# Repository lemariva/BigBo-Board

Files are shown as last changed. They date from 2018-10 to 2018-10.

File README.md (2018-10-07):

# BigBo-Board

BigBo is a multi-target board for Energy Metering & Power Monitoring. It's the big brother of [PiCoBo](https://github.com/lemariva/PiCoBo-Board). I designed it using the MSP430F5529LP that is part of the MSP430 Texas Instruments family of low-power microcontrollers.

More info will be available on https://lemariva.com soon.

## Components
The board includes:
* CP2102 for UART communication (with ESD-Protection)
* Socket for a NRF24L01 module
* CD4504B: level shifter
* BQ27510-Q3: battery fuel gauge
* BQ24210DQCT: Li-Ion battery charger
* CAT24FC32UI: EEPROM memory
* TPS6300x: buck-boost converters (for 5V)
* MCP39F501: power-monitoring
* etc.

This board is a Energy Metering & Power Monitoring demonstration board with communication possibilities (0.1% error across 4000:1 dynamic range). I designed it near 2013, when home solutions were limited and expensive. The power energy metering & power monitoring functions are based on the [ARD00455](https://www.microchip.com/Developmenttools/ProductDetails/ARD00455) board.

The board can be supplied using:
* a battery (Li-Ion) which can be also charged
* 5V over the micro-usb connector
* 230V AC (not a typo error - 230V AC!). The floating 3.3V is generated using a LM1117. Check the HIGH-Voltage page on the schematic.

Additionally multiple pinouts are available to connect external sensors (e.g. DHT11), servo motors, LEDs etc. For testing uses it can be programmed using the MSP430F5529LP LaunchPad.

## PCB
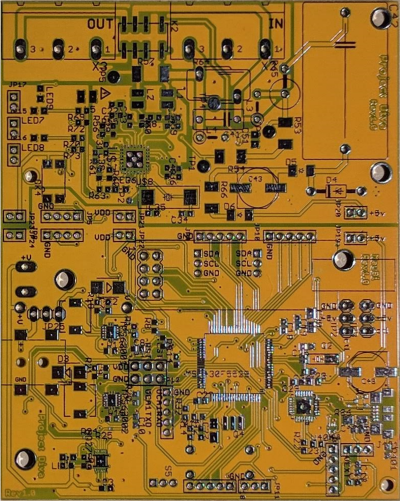
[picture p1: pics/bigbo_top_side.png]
PCB Board Top Side
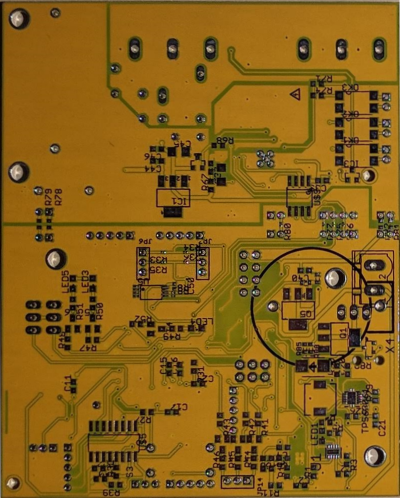
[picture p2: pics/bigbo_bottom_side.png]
PCB Board Bottom Side
|||
|:- |:-|

### Applications
* Energy Metering & Power Monitoring
* Smart switch
* Sensor measurement (Temperature etc.)
* LEDs control
* Communication
* etc.

### Revision
* 1.0 first version

### Disclaimer
Use at your own risk and be careful specially with the 230V AC part.

I ordered the board (I have 10 PCBs over here) but I didn't have enough time to solder the components. I've checked the design many times but errors could be over there. I'll be updating the code that I had for the board soon.

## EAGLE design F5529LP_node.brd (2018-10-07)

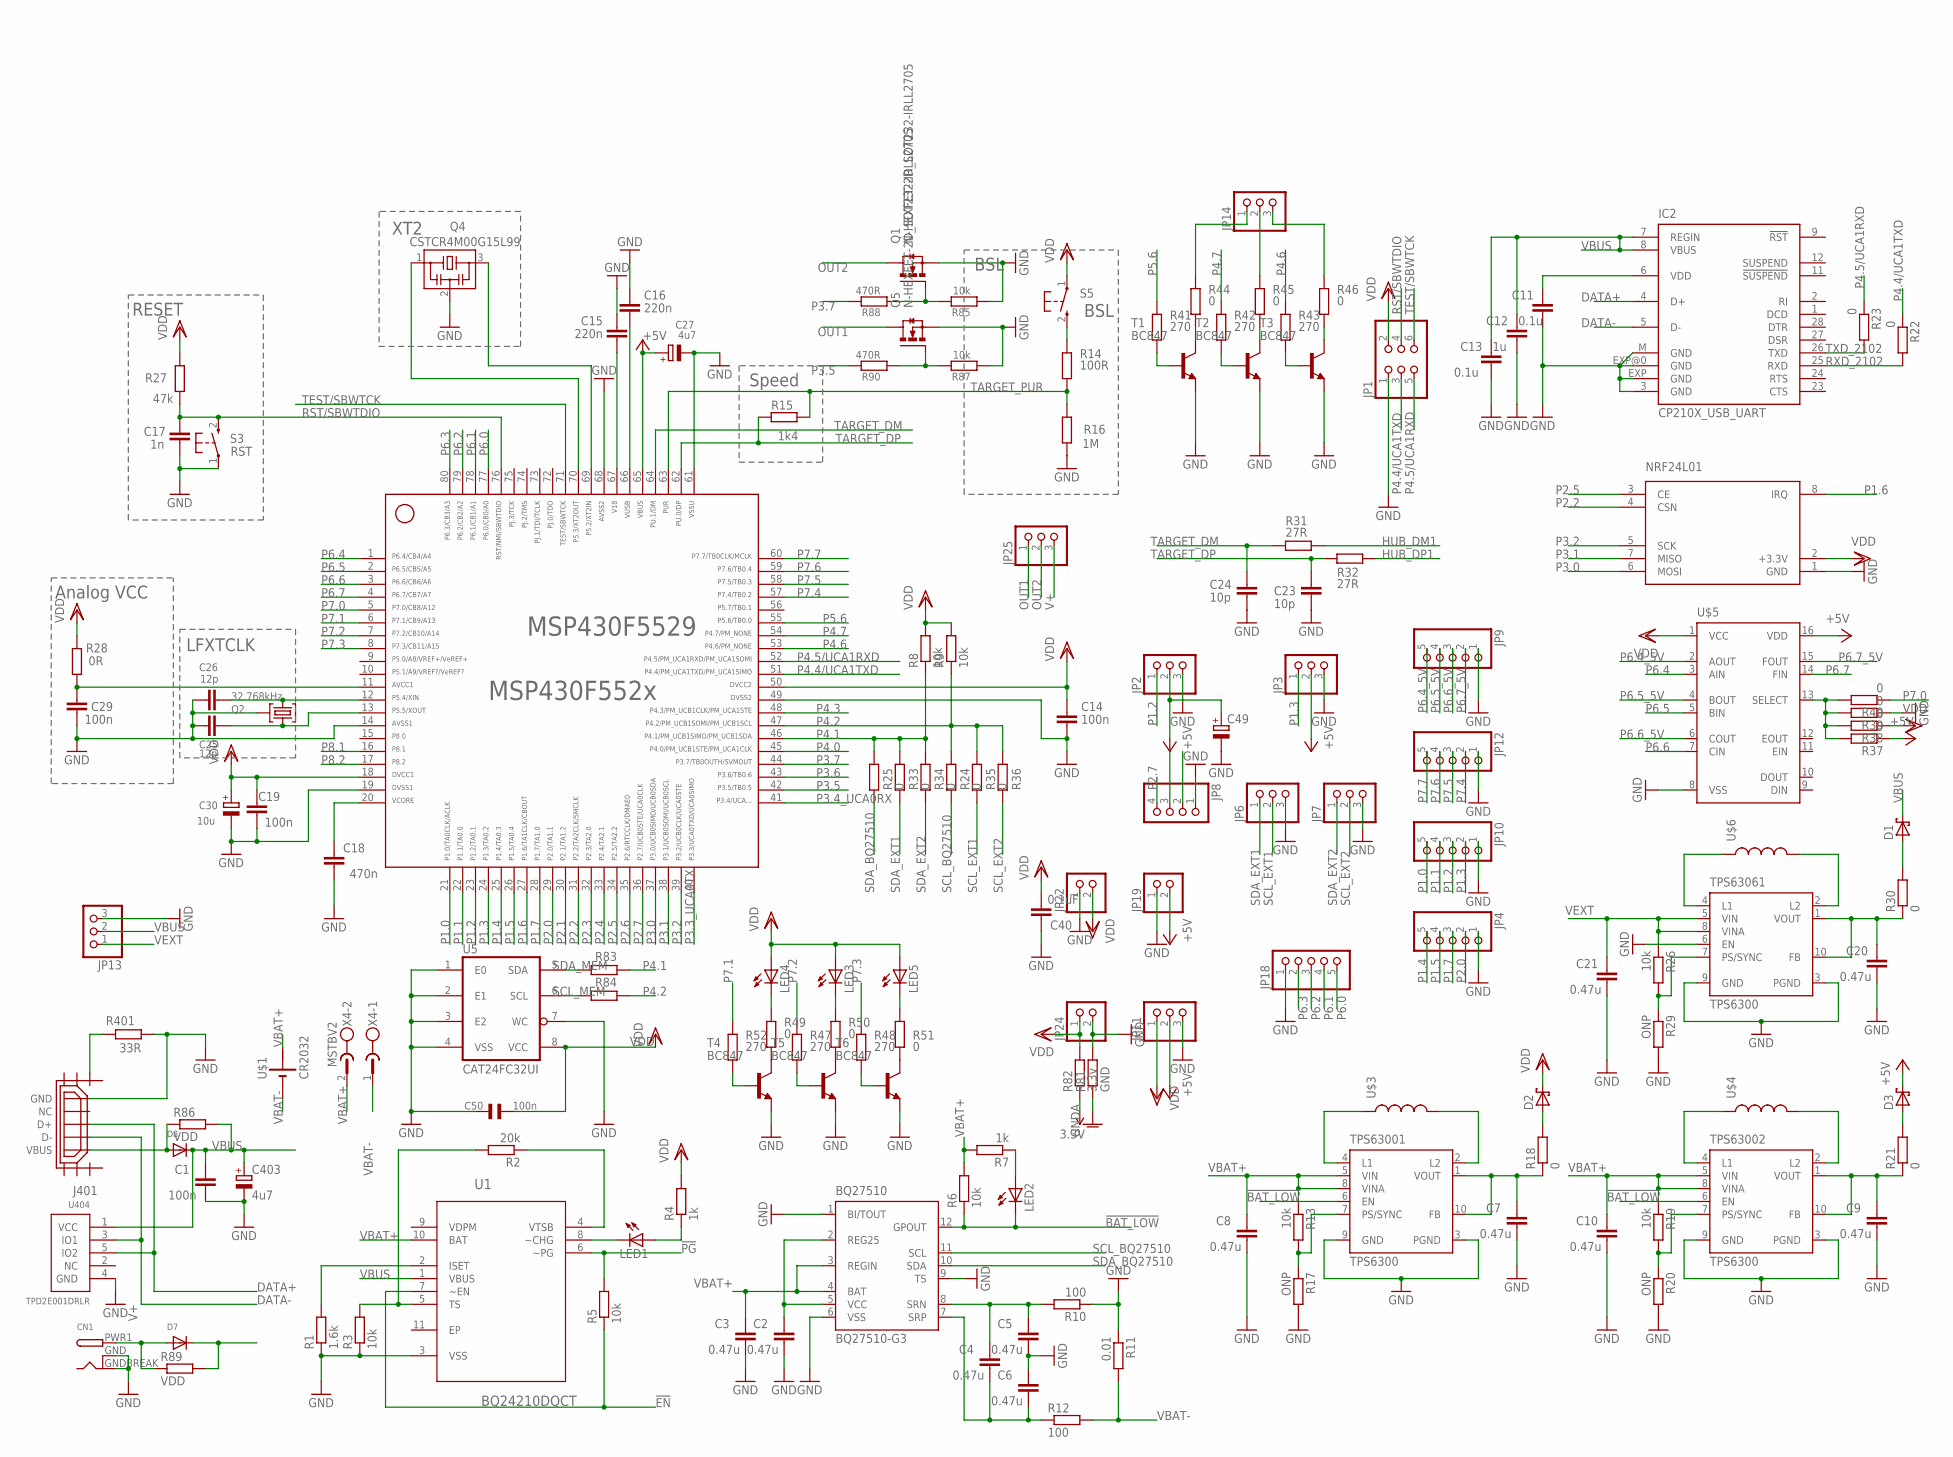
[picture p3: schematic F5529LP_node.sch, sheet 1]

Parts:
BQ27510: BQ27510-G3; DRZ
C1, C14, C19, C29: 100n; C0603
C2, C3, C4, C5, C6, C7, C8, C9, C10, C20, C21: 0.47u; C0603
C11, C13: 0.1u; C0603
C12: 1u; C0603
C15, C16: 220n; C0603
C17: 1n; C0603
C18: 470n; C0603
C23, C24: 10p; C0603
C25, C26: 12p; C0603
C27, C403: 4u7; A/3216-18R
C30: 10u; A/3216-18R
C40: 0.1uF; C0603
C49: CPOL-EUF; PANASONIC_F
C50: 100n; 0402
CN1: DCBARRELSMT; DCJACK_2MM_SMT
D1, D2, D3: SCHOTTKY-DIODE; DIODE_SMB
D7, D8: DIODESOT23_REFLOW; SOT23-R
IC2: CP210X_USB_UART; MLP28
J401: USB_MICRO_FLIPPED; HIROSE-ZX62R-B-5P
JP1: PINHD-2X3; 2X03
JP2, JP3, JP25: PINHD-1X3; 1X03
JP4, JP9, JP10, JP12, JP18: PINHD-1X5_2.00; 1X05M
JP6, JP7, JP11, JP13, JP14: PINHD-1X3_2.00; 1X03M
JP8: PINHD-1X4_2.00; 1X04M
JP19, JP22, JP24: PINHD-1X2_2.00; 1X02M
LED1, LED2, LED3, LED4, LED5: LEDSML0805; SML0805
MSP430F5529: MSP430F5529IPNR; PN80
NRF24L01: NRF24L01HP; NRF24L01_HP
Q1, Q5: N-HEXFET-2D_SOT232-IRLL2705; SOT223
Q2: 32.768kHz; MS3V-T1R
Q4: CSTCR4M00G15L99; MURATA-FILTER_CSTCR
R1: 1.6k; R0603
R2: 20k; R0603
R3, R5, R6, R8, R9, R13, R19, R26: 10k; R0603
R4, R7: 1k; R0603
R10, R12: 100; R0603
R11: 0.01; R0603
R14: 100R; R0603
R15: 1k4; R0603
R16: 1M; R0603
R17, R20, R29: ONP; R0603
R18, R21, R22, R23, R30, R37, R38, R39, R40, R44, R45, R46, R49, R50, R51: 0; R0603
R24, R25, R33, R34, R35, R36, R83, R84: 0; R0201
R27: 47k; R0603
R28: 0R; R0603
R31, R32: 27R; R0603
R41, R42, R43, R47, R48, R52: 270; R0603
R81: GND; R0402
R82: 3.3v; R0402
R85, R87: 10k; 0603
R86, R89: VDD; R0201
R88, R90: 470R; 0603
R401: 33R; R0603
S3: RST; PBTH
S5: BSL; PBTH
T1, T2, T3, T4, T5, T6: BC847; SOT23
TPS63001, TPS63002, TPS63061: TPS6300; DRC-S-PVSON-N10
U1: BQ24210DQCT; SON50P200X300X80-11N
U5: CAT24FC32UI; TSSOP8
U404: TPD2E001DRLR; TPD2E001-DRL
U$1: CR2032
U$3, U$4, U$6: INDUCTOR-B82462G; B82462G
U$5: CD4504B; SOIC16
X4: MSTBV2

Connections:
3.3V: R82.1; also elsewhere on the board
!BAT_LOW: BQ27510.12 (GPOUT), LED2.C, R6.1, TPS63001.6 (EN), TPS63002.6 (EN)
!EN: R5.1, U1.7 (~EN)
!PG: R5.2, U1.6 (~PG)
+5V: C27.+, C49.+, D3.C (A), JP2.2, JP3.2, JP11.2, JP19.2, MSP430F5529.65, R37.1, U$5.16 (VDD); also elsewhere on the board
AVCC: C29.1, MSP430F5529.11, R28.1
DATA+: IC2.4 (D+), J401.D+, U404.5 (IO2)
DATA-: IC2.5 (D-), J401.D-, U404.3 (IO1)
GND: BQ27510.1 (BI/TOUT), BQ27510.6 (VSS), BQ27510.9 (TS), C1.2, C2.2, C3.2, C5.2, C6.1, C7.2, C8.2, C9.2, C10.2, C11.2, C12.2, C13.2, C14.2, C15.2, C16.2, C17.2, C18.1, C19.1, C20.2, C21.2, C23.2, C24.2, C25.1, C26.1, C27.-, C29.2, C30.-, C40.1, C49.-, C50.2, C403.-, CN1.GND (GNDBREAK), CN1.GNDBREAK (GND), IC2.3 (GND), IC2.EXP (GND), IC2.EXP@0 (GND), IC2.M (GND), J401.GND, JP1.1, JP2.3, JP3.3, JP4.1, JP6.3, JP7.3, JP8.1, JP9.1, JP10.1, JP11.3, JP12.1, JP13.3, JP18.1, JP19.1, JP22.1, JP24.2, MSP430F5529.14, MSP430F5529.19, MSP430F5529.49, MSP430F5529.61, MSP430F5529.68, NRF24L01.1 (GND), Q1.3 (S), Q2.P3 (GND), Q4.2, Q5.3 (S), R1.1, R3.1, R10.1, R11.1, R16.1, R17.2, R20.2, R29.2, R39.1, R81.2, R85.1, R87.1, R401.2, S3.1, T1.2 (E), T2.2 (E), T3.2 (E), T4.2 (E), T5.2 (E), T6.2 (E), TPS63001.3 (PGND), TPS63001.9 (GND), TPS63002.3 (PGND), TPS63002.9 (GND), TPS63061.3 (PGND), TPS63061.6 (EN), TPS63061.9 (GND), U1.3 (VSS), U5.1 (E0), U5.2 (E1), U5.3 (E2), U5.4 (VSS), U5.7 (WC), U404.4 (GND), U$5.8 (VSS); also elsewhere on the board
GNDA: R81.1; also elsewhere on the board
HUB_DM1: R31.1
HUB_DP1: R32.1
unnamed: R1.2, U1.2 (ISET)
unnamed: R2.1, U1.4 (VTSB)
unnamed: R2.2, R3.2, U1.5 (TS)
unnamed: R14.1, S5.2 (S)
unnamed: LED1.C, U1.8 (~CHG)
unnamed: LED1.A, R4.1
unnamed: BQ27510.2 (REG25), BQ27510.5 (VCC), C2.1
unnamed: TPS63002.4 (L1), U$4.P$1 (1)
unnamed: LED2.A, R7.1
unnamed: J401.SHIELD1, R401.1
unnamed: BQ27510.8 (SRN), C4.1, C5.1, R10.2
unnamed: TPS63001.4 (L1), U$3.P$1 (1)
unnamed: TPS63001.2 (L2), U$3.P$2 (2)
unnamed: BQ27510.7 (SRP), C4.2, C6.2, R12.1
unnamed: TPS63002.2 (L2), U$4.P$2 (2)
unnamed: R13.2, R17.1, TPS63001.7 (PS/SYNC)
unnamed: R19.2, R20.1, TPS63002.7 (PS/SYNC)
unnamed: C9.1, R21.1, TPS63002.1 (VOUT), TPS63002.10 (FB)
unnamed: C7.1, R18.1, TPS63001.1 (VOUT), TPS63001.10 (FB)
unnamed: C11.1, IC2.6 (VDD)
unnamed: TPS63061.4 (L1), U$6.P$1 (1)
unnamed: TPS63061.2 (L2), U$6.P$2 (2)
unnamed: R26.2, R29.1, TPS63061.7 (PS/SYNC)
unnamed: C20.1, R30.1, TPS63061.1 (VOUT), TPS63061.10 (FB)
unnamed: R37.2, R38.2, R39.2, R40.2, U$5.13 (SELECT)
unnamed: R41.2, T1.1 (B)
unnamed: R42.2, T2.1 (B)
unnamed: R43.2, T3.1 (B)
unnamed: R46.2, T3.3 (C)
unnamed: JP14.1, R44.1
unnamed: JP14.2, R45.1
unnamed: JP14.3, R46.1
unnamed: R44.2, T1.3 (C)
unnamed: R45.2, T2.3 (C)
unnamed: D1.A (C), R30.2
unnamed: D2.A (C), R18.2
unnamed: D3.A (C), R21.2
unnamed: R47.2, T5.1 (B)
unnamed: R48.2, T6.1 (B)
unnamed: R51.2, T6.3 (C)
unnamed: LED4.C, R49.1
unnamed: LED3.C, R50.1
unnamed: LED5.C, R51.1
unnamed: R49.2, T4.3 (C)
unnamed: R50.2, T5.3 (C)
unnamed: R52.2, T4.1 (B)
unnamed: Q1.1 (G), R85.2, R88.1
unnamed: D8.1 (A), J401.VBUS, R86.1
unnamed: Q5.1 (G), R87.2, R90.1
OUT1: JP25.1, Q5.2 (D), Q5.4 (D)
OUT2: JP25.2, Q1.2 (D), Q1.4 (D)
P1.0: JP10.5, MSP430F5529.21
P1.1: JP10.4, MSP430F5529.22
P1.2: JP2.1, JP10.3, MSP430F5529.23
P1.3: JP3.1, JP10.2, MSP430F5529.24
P1.4: JP4.5, MSP430F5529.25
P1.5: JP4.4, MSP430F5529.26
P1.6: MSP430F5529.27, NRF24L01.8 (IRQ)
P1.7: JP4.3, MSP430F5529.28
P2.0: JP4.2, MSP430F5529.29
P2.1: MSP430F5529.30
P2.2: MSP430F5529.31, NRF24L01.4 (CSN)
P2.3: MSP430F5529.32
P2.4: MSP430F5529.33
P2.5: MSP430F5529.34, NRF24L01.3 (CE)
P2.6: MSP430F5529.35
P2.7: JP8.4, MSP430F5529.36; also elsewhere on the board
P3.0: MSP430F5529.37, NRF24L01.6 (MOSI)
P3.1: MSP430F5529.38, NRF24L01.7 (MISO)
P3.2: MSP430F5529.39, NRF24L01.5 (SCK)
P3.3_UCA0TX: JP8.2, MSP430F5529.40; also elsewhere on the board
P3.4_UCA0RX: JP8.3, MSP430F5529.41; also elsewhere on the board
P3.5: MSP430F5529.42, R90.2
P3.6: MSP430F5529.43
P3.7: MSP430F5529.44, R88.2
P4.0: MSP430F5529.45
P4.1: MSP430F5529.46, R8.1, R25.1, R33.1, R34.1, R83.2
P4.2: MSP430F5529.47, R9.1, R24.1, R35.1, R36.1, R84.2
P4.3: MSP430F5529.48
P4.4/UCA1TXD: JP1.3, MSP430F5529.51, R22.1
P4.5/UCA1RXD: JP1.5, MSP430F5529.52, R23.1
P4.6: MSP430F5529.53, R43.1
P4.7: MSP430F5529.54, R42.1
P5.2/XT2IN: MSP430F5529.69, Q4.3
P5.3/XT2OUT: MSP430F5529.70, Q4.1
P5.4/XIN: C26.2, MSP430F5529.12, Q2.P2 (2)
P5.5/XOUT: C25.2, MSP430F5529.13, Q2.P1 (1)
P5.6: MSP430F5529.55, R41.1
P6.0: JP18.5, MSP430F5529.77
P6.1: JP18.4, MSP430F5529.78
P6.2: JP18.3, MSP430F5529.79
P6.3: JP18.2, MSP430F5529.80
P6.4: MSP430F5529.1, U$5.3 (AIN)
P6.4_5V: JP9.5, U$5.2 (AOUT)
P6.5: MSP430F5529.2, U$5.5 (BIN)
P6.5_5V: JP9.4, U$5.4 (BOUT)
P6.6: MSP430F5529.3, U$5.7 (CIN)
P6.6_5V: JP9.3, U$5.6 (COUT)
P6.7: MSP430F5529.4, U$5.14 (FIN)
P6.7_5V: JP9.2, U$5.15 (FOUT)
P7.0: MSP430F5529.5, R40.1
P7.1: MSP430F5529.6, R52.1
P7.2: MSP430F5529.7, R47.1
P7.3: MSP430F5529.8, R48.1
P7.4: JP12.2, MSP430F5529.57
P7.5: JP12.3, MSP430F5529.58
P7.6: JP12.4, MSP430F5529.59
P7.7: JP12.5, MSP430F5529.60
P8.1: MSP430F5529.16
P8.2: MSP430F5529.17
PWPD: BQ27510.EXP@1 (PWPD), BQ27510.EXP@2 (PWPD), BQ27510.EXP@3 (PWPD), BQ27510.EXP@4 (PWPD), BQ27510.EXP@5 (PWPD), BQ27510.EXP@6 (PWPD), BQ27510.EXP@7 (PWPD), BQ27510.EXP@8 (PWPD), BQ27510.EXP@9 (PWPD)
RST/SBWTDIO: C17.1, JP1.4, MSP430F5529.76, R27.1, S3.2 (S)
RXD_2102: IC2.25 (RXD), R22.2
SCL_BQ27510: BQ27510.11 (SCL), R24.2
SCL_EXT1: JP6.2, R35.2
SCL_EXT2: JP7.2, R36.2
SCL_MEM: R84.1, U5.6 (SCL)
SDA_BQ27510: BQ27510.10 (SDA), R25.2
SDA_EXT1: JP6.1, R33.2
SDA_EXT2: JP7.1, R34.2
SDA_MEM: R83.1, U5.5 (SDA)
TARGET_DM: C24.1, MSP430F5529.64, R31.2
TARGET_DP: C23.1, MSP430F5529.62, R15.2, R32.2
TARGET_PUR: MSP430F5529.63, R14.2, R15.1, R16.2
TARGET_VUSB: C16.1, MSP430F5529.66
TEST/SBWTCK: JP1.6, MSP430F5529.71
TXD_2102: IC2.26 (TXD), R23.2
V18: C15.1, MSP430F5529.67
V+: CN1.PWR1 (PWR), D7.1 (A), JP25.3, R89.1
VBAT+: BQ27510.3 (REGIN), BQ27510.4 (BAT), C3.1, C8.1, C10.1, R6.2, R7.2, R13.1, R19.1, TPS63001.5 (VIN), TPS63001.8 (VINA), TPS63002.5 (VIN), TPS63002.8 (VINA), U1.10 (BAT), U$1.P$1 (+), X4.2
VBAT-: R11.2, R12.2, U$1.P$2 (-), X4.1
VBUS: C1.1, C12.1, C13.1, C403.+, D1.C (A), D7.3 (C), D8.3 (C), IC2.7 (REGIN), IC2.8 (VBUS), JP13.2, R86.2, R89.2, U1.1 (VBUS), U404.1 (VCC)
VCORE: C18.2, MSP430F5529.20
VDD: C14.1, C19.2, C30.+, C40.2, C50.1, D2.C (A), JP1.2, JP11.1, JP22.2, JP24.1, LED3.A, LED4.A, LED5.A, MSP430F5529.18, MSP430F5529.50, NRF24L01.2 (+3.3V), R4.2, R8.2, R9.2, R27.2, R28.2, R38.1, R82.2, S5.1, U5.8 (VCC), U$5.1 (VCC); also elsewhere on the board
VEXT: C21.1, JP13.1, R26.1, TPS63061.5 (VIN), TPS63061.8 (VINA)

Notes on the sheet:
RESET
LFXTCLK
XT2
BSL
Speed
Analog VCC

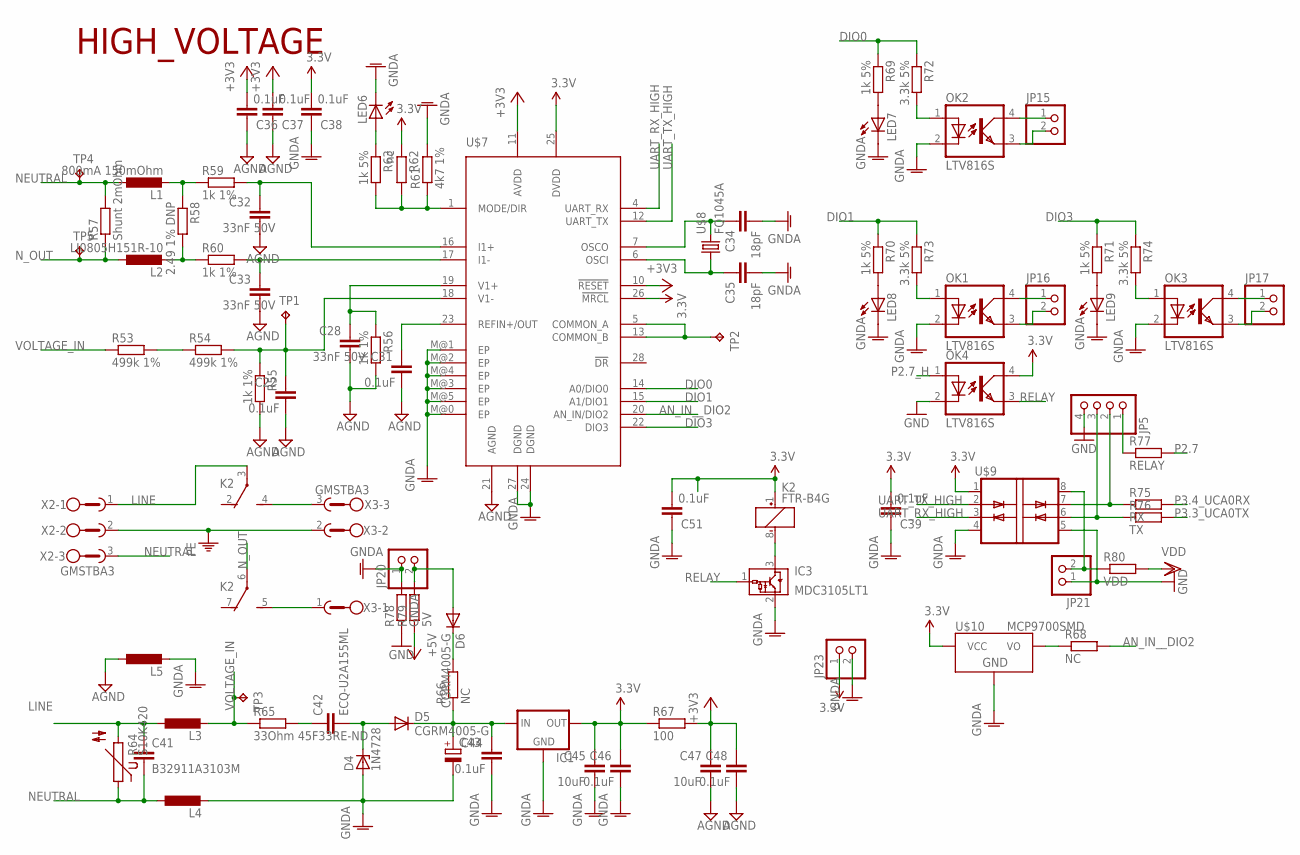
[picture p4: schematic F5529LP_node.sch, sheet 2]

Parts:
C22, C31, C36, C37, C38, C39, C44, C46, C48: 0.1uF; C0603
C28, C32, C33: 33nF 50V; C0603
C34, C35: 18pF; C0603
C41: B32911A3103M; C075-042X103
C42: ECQ-U2A155ML; C275-173X316
C43: CPOL-EUF; PANASONIC_F
C45, C47: 10uF; C1206
C51: 0.1uF; C0805
D4: 1N4728; DO41Z10
D5, D6: CGRM4005-G; SOD-123_MINI-SMA
IC1: LM1117; SOT223
IC3: MDC3105LT1; SOT23
JP5: PINHD-1X4_2.00; 1X04M
JP15, JP16, JP17, JP20, JP21, JP23: PINHD-1X2_2.00; 1X02M
K2: FTR-B4G
L1: 800mA 150mOhm; L2825P
L2: LI0805H151R-10; L2825P
L3, L4: L-EU0207/5V; 0207/5V
L5: L-EUL2825P; L2825P
LED6, LED7, LED8, LED9: LEDCHIPLED_0805; CHIPLED_0805
OK1, OK2, OK3, OK4: LTV816S; SMD4
R53, R54: 499k 1%; R2010
R55, R56, R59, R60: 1k 1%; R0603
R57: Shunt 2mOhm; R2512
R58: 2.49 1% DNP; R0603
R61: 4k7 1%; R0603
R62: nc; R0603
R63, R69, R70, R71: 1k 5%; R0603
R64: S10K420
R65: 33Ohm 45F33RE-ND; 0617V
R66: NC; R2010
R67: 100; R0603
R68: NC; R0603
R72, R73, R74: 3.3k 5%; R0603
R75: RX; R0201
R76: TX; R0201
R77: RELAY; R0201
R78: GNDA; R0402
R79: 5V; R0402
R80: VDD; R0201
TP1, TP3, TP4, TP5: TPB2,54; B2,54
TP2: TPB1,27; B1,27
U$7: MCP39F501; QFN28
U$8: FQ1045A
U$9: IL712; SOIC08
U$10: MCP9700SMD; SOT23-3
U$11: HIGH_VOLTAGE
X2, X3: GMSTBA3

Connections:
3.3V: C38.2, C39.2, C45.1, C46.1, C51.2, IC1.2 (OUT), JP23.1, K2.1 (+), OK4.4 (COL), R62.1, R67.1, U$7.25 (DVDD), U$7.26 (!MRCL), U$9.1 (VDD1), U$10.1 (VCC); also elsewhere on the board
!DR: U$7.28 (!DR)
+3V3: C36.2, C37.2, C47.1, C48.1, R67.2, U$7.10 (!RESET), U$7.11 (AVDD)
+5V: R79.1; also elsewhere on the board
AGND: C22.2, C28.2, C31.2, C32.2, C33.2, C36.1, C37.1, C47.2, C48.2, L5.1, R55.2, R56.2, U$7.21 (AGND)
AN_IN__DIO2: R68.2, U$7.20 (AN_IN/DIO2)
DIO0: R69.1, R72.1, U$7.14 (A0/DIO0)
DIO1: R70.1, R73.1, U$7.15 (A1/DIO1)
DIO3: R71.1, R74.1, U$7.22 (DIO3)
GND: JP5.4, JP21.1, OK4.2 (C), R78.1, U$9.5 (GND2); also elsewhere on the board
GNDA: C34.2, C35.2, C38.1, C39.1, C43.-, C44.2, C45.2, C46.2, C51.1, D4.A, IC1.1 (GND), IC3.2 (GND), JP20.1, JP23.2, L4.2, L5.2, LED6.C, LED7.C, LED8.C, LED9.C, OK1.2 (C), OK2.2 (C), OK3.2 (C), R61.2, R78.2, U$7.24 (DGND), U$7.27 (DGND), U$7.M@0 (EP), U$7.M@1 (EP), U$7.M@2 (EP), U$7.M@3 (EP), U$7.M@4 (EP), U$7.M@5 (EP), U$9.4 (GND1), U$10.3 (GND); also elsewhere on the board
LINE: C41.1, K2.3, L3.1, R64.2, X2.1
LINE_RELAY: K2.4 (S), X3.3
unnamed: LED8.A, R70.2
unnamed: R53.2, R54.1
unnamed: C22.1, R54.2, R55.1, TP1.TP, U$7.18 (V1-)
unnamed: C28.1, R56.1, U$7.19 (V1+)
unnamed: C31.1, U$7.23 (REFIN+/OUT)
unnamed: LED7.A, R69.2
unnamed: LED9.A, R71.2
unnamed: L1.2, R58.1, R59.1
unnamed: L2.2, R58.2, R60.1
unnamed: C33.1, R60.2, U$7.17 (I1-)
unnamed: C32.1, R59.2, U$7.16 (I1+)
unnamed: R61.1, R62.2, R63.2, U$7.1 (MODE/DIR)
unnamed: LED6.A, R63.1
unnamed: C34.1, U$7.7 (OSCO), U$8.2 (3)
unnamed: C35.1, U$7.6 (OSCI), U$8.1
unnamed: C43.+, C44.1, D5.C, IC1.3 (IN), R66.1
unnamed: D6.C, R66.2
unnamed: OK2.1 (A), R72.2
unnamed: TP2.TP, U$7.5 (COMMON_A), U$7.13 (COMMON_B)
unnamed: R68.1, U$10.2 (VO)
unnamed: C42.2, D4.C, D5.A
unnamed: C42.1, R65.2
unnamed: OK1.1 (A), R73.2
unnamed: OK3.1 (A), R74.2
unnamed: JP5.2, R75.1, U$9.7 (OUT1)
unnamed: JP5.3, R76.1, U$9.6 (IN2)
unnamed: JP15.1, OK2.4 (COL)
unnamed: JP15.2, OK2.3 (EMIT)
unnamed: JP16.1, OK1.4 (COL)
unnamed: JP16.2, OK1.3 (EMIT)
unnamed: JP17.1, OK3.4 (COL)
unnamed: JP17.2, OK3.3 (EMIT)
unnamed: IC3.3 (VOUT), K2.8 (-)
unnamed: D6.A, JP20.2, R79.2
unnamed: JP21.2, R80.1, U$9.8 (VDD2)
NEUTRAL: C41.2, L1.1, L4.1, R57.2, R64.1, TP4.TP, X2.3
NEUTRAL_RELAY: K2.5 (S), X3.1
N_OUT: K2.6, L2.1, R57.1, TP5.TP
P2.7: R77.2; also elsewhere on the board
P2.7_H: JP5.1, OK4.1 (A), R77.1
P3.3_UCA0TX: R76.2; also elsewhere on the board
P3.4_UCA0RX: R75.2; also elsewhere on the board
PE: X2.2, X3.2
RELAY: IC3.1 (VIN), OK4.3 (EMIT)
UART_RX_HIGH: U$7.4 (UART_RX), U$9.3 (OUT2)
UART_TX_HIGH: U$7.12 (UART_TX), U$9.2 (IN1)
VDD: R80.2; also elsewhere on the board
VOLTAGE_IN: L3.2, R53.1, R65.1, TP3.TP

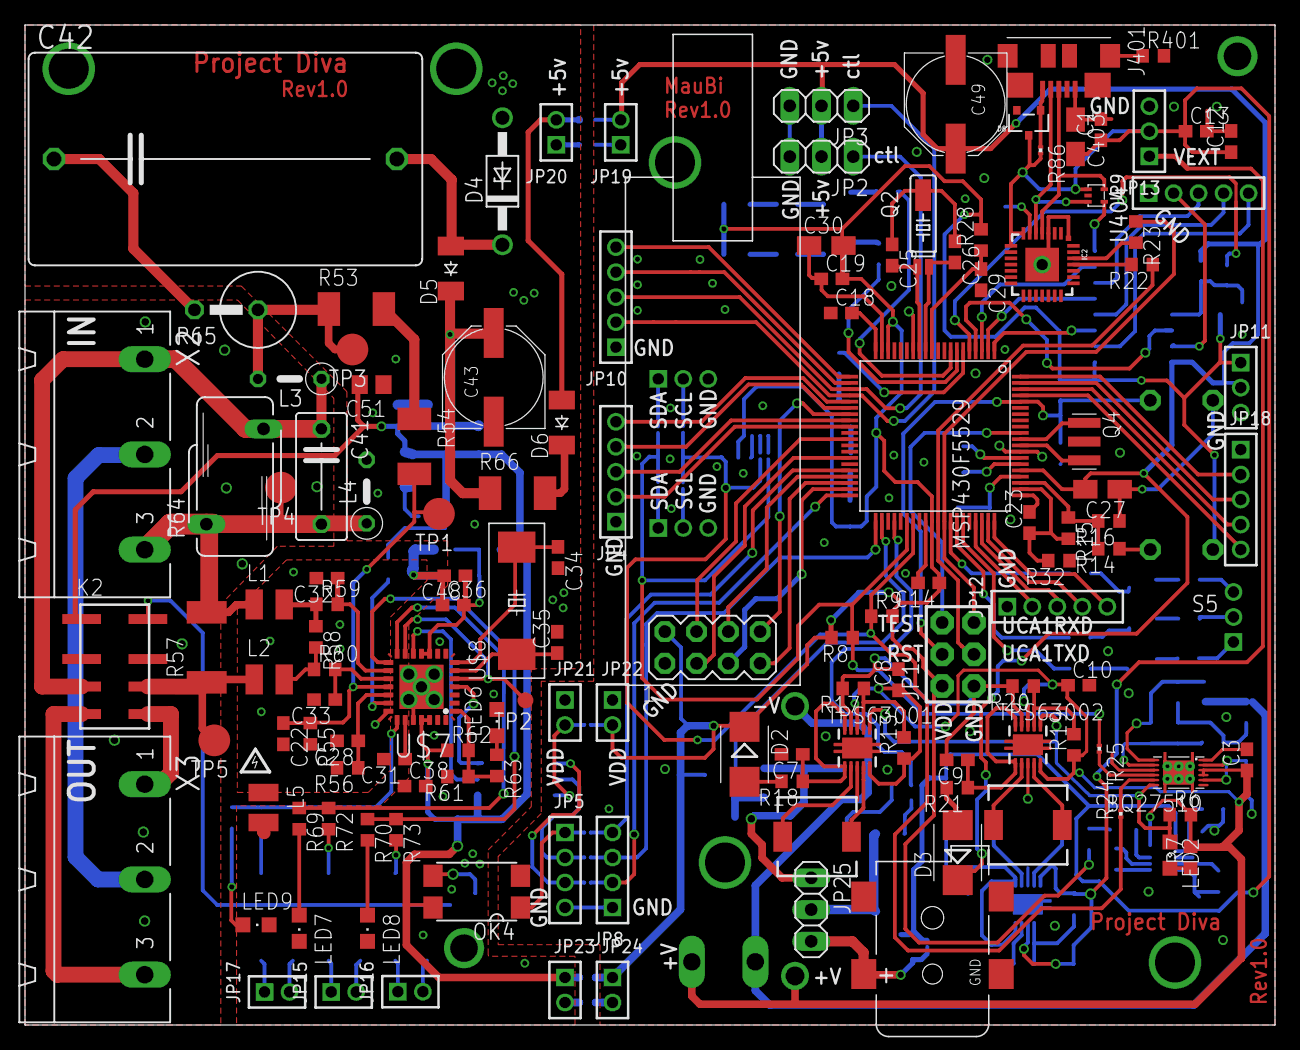
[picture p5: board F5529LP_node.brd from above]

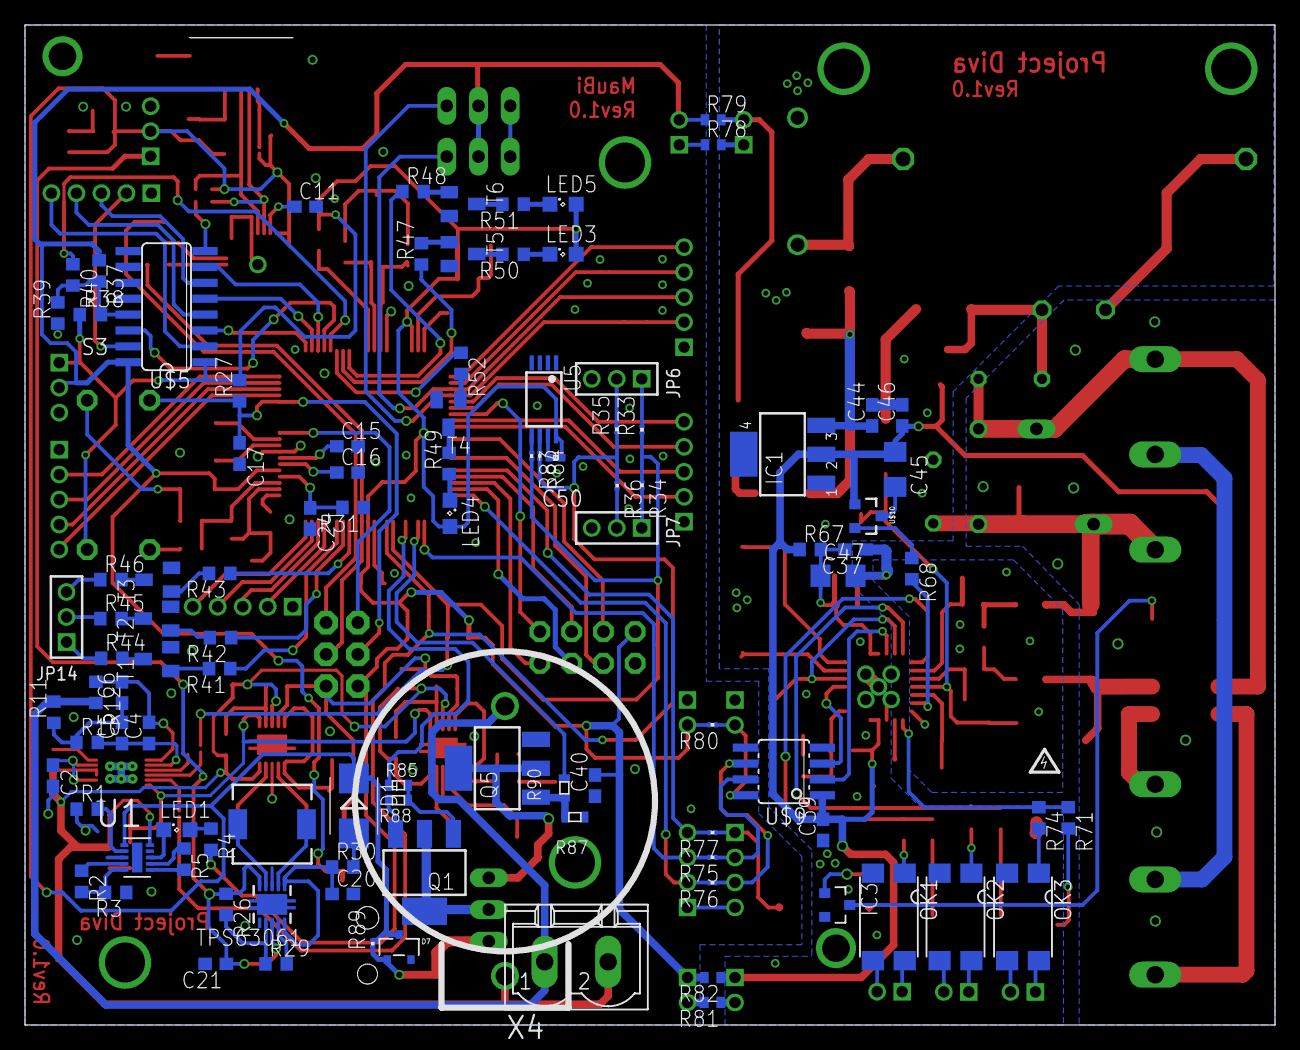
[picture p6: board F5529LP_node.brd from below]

Board: 2 copper layers, 100.0 x 80.0 mm, 240 parts (104 on the bottom side), 188 nets.

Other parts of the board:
U$12: HIGH_VOLTAGE
